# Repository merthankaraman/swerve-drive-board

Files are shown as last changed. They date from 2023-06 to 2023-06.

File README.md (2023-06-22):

# Swerve Drive Mobile Robot Board
### Schematic Of the Shield V2
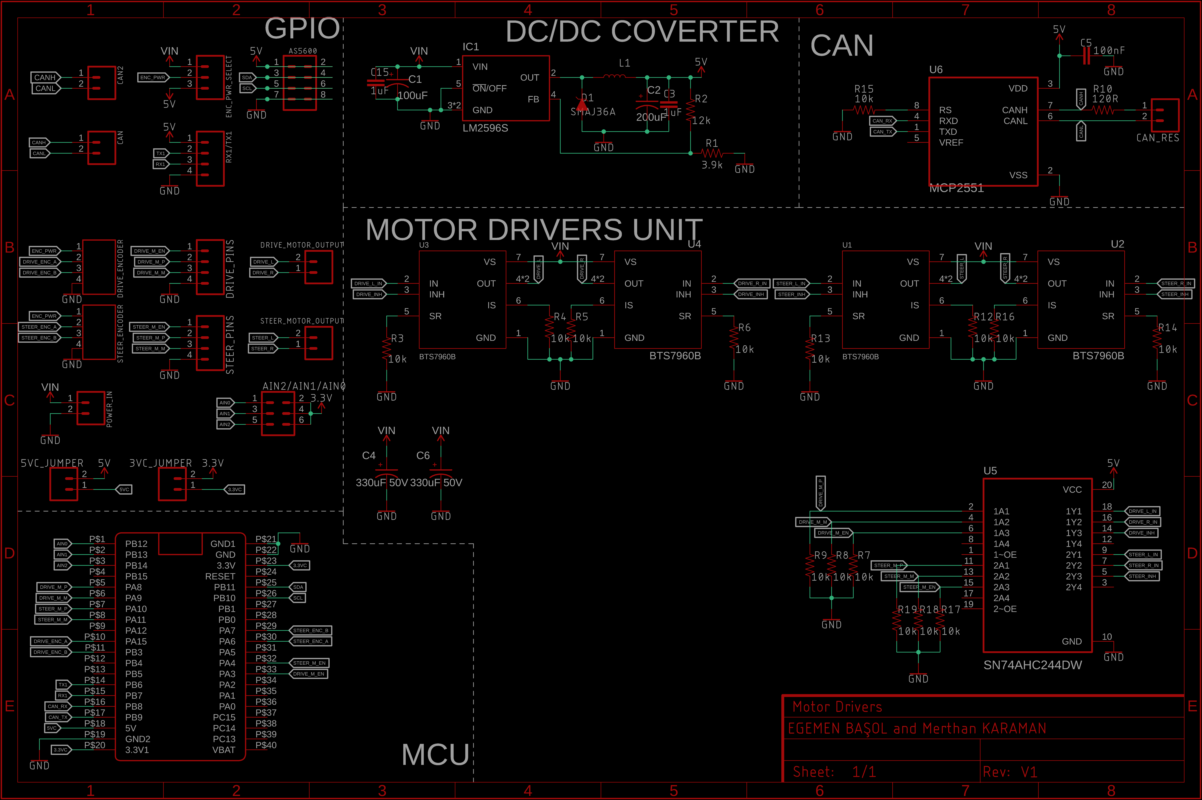
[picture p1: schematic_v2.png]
<br/><br/>

### Board Of the Shield V2
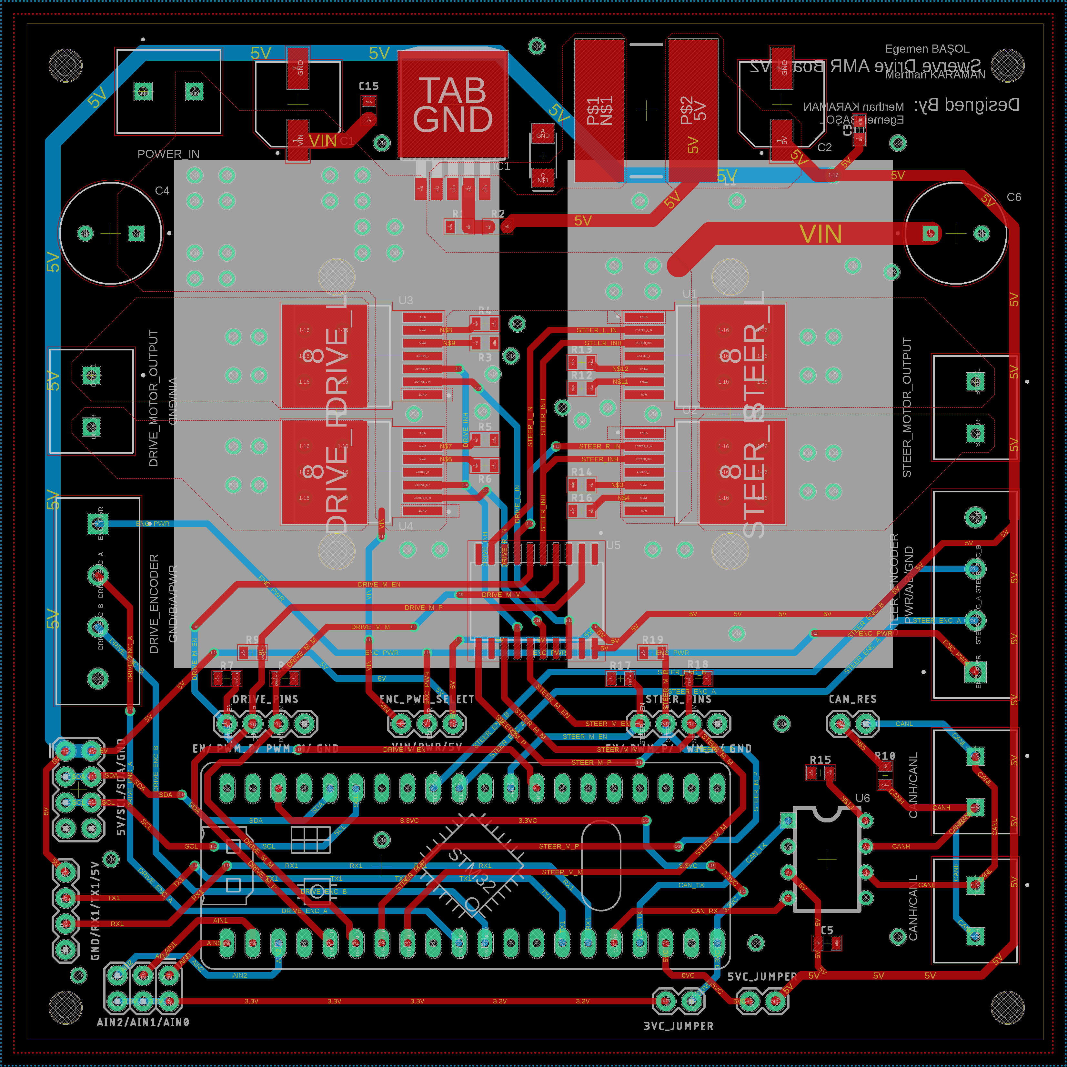
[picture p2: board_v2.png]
<br/><br/>

### Schematic Of the Shield V1
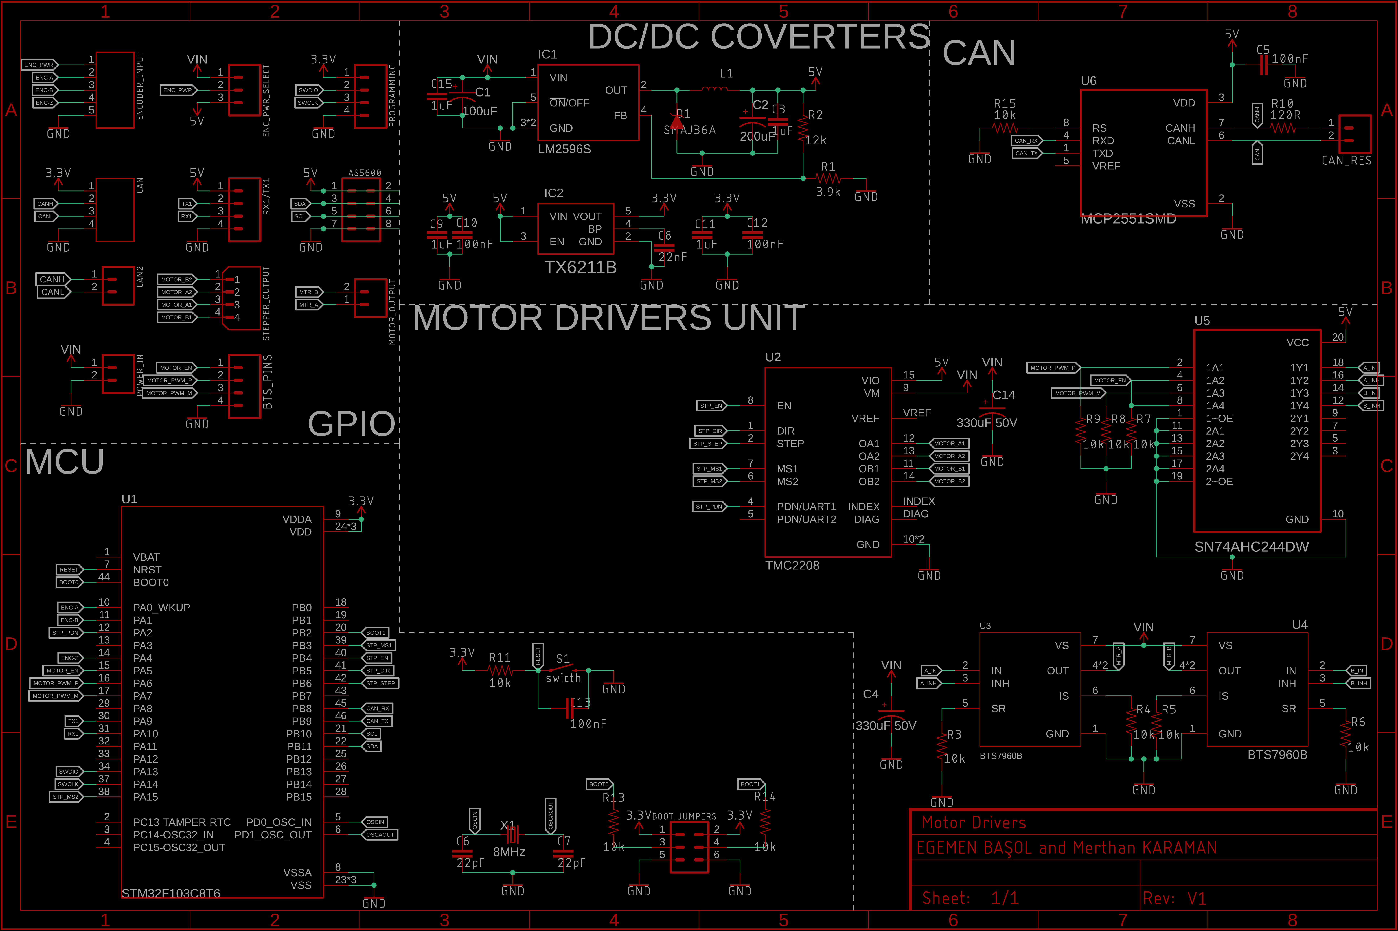
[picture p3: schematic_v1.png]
<br/><br/>

### Board Of the Shield V1
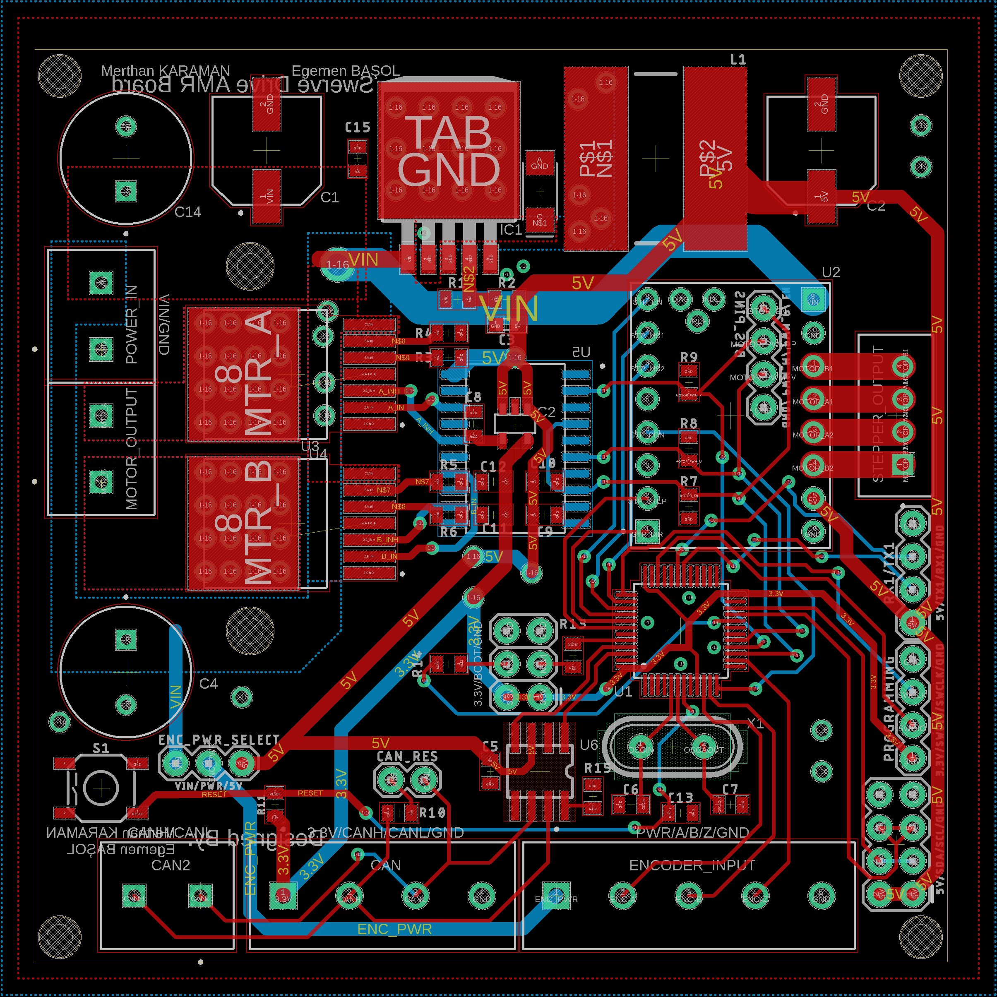
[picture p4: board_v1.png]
<br/><br/>

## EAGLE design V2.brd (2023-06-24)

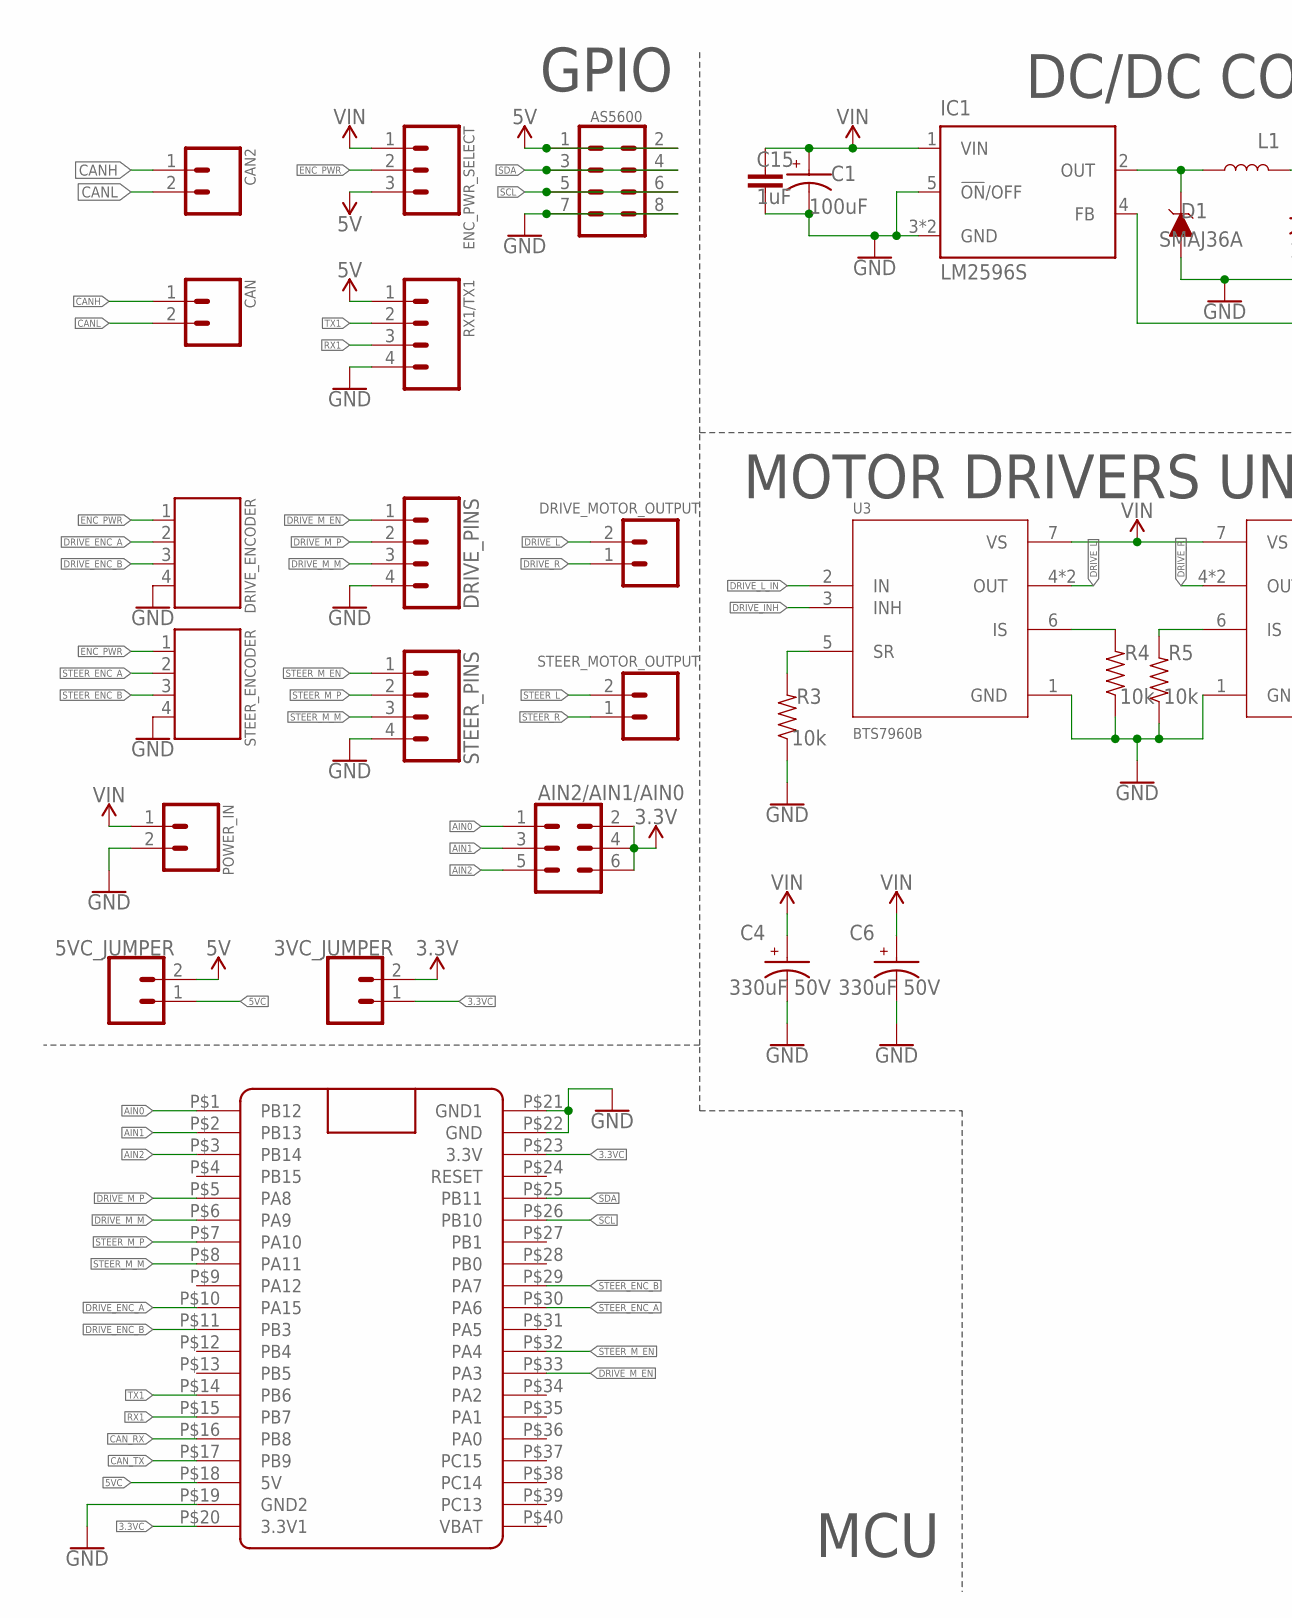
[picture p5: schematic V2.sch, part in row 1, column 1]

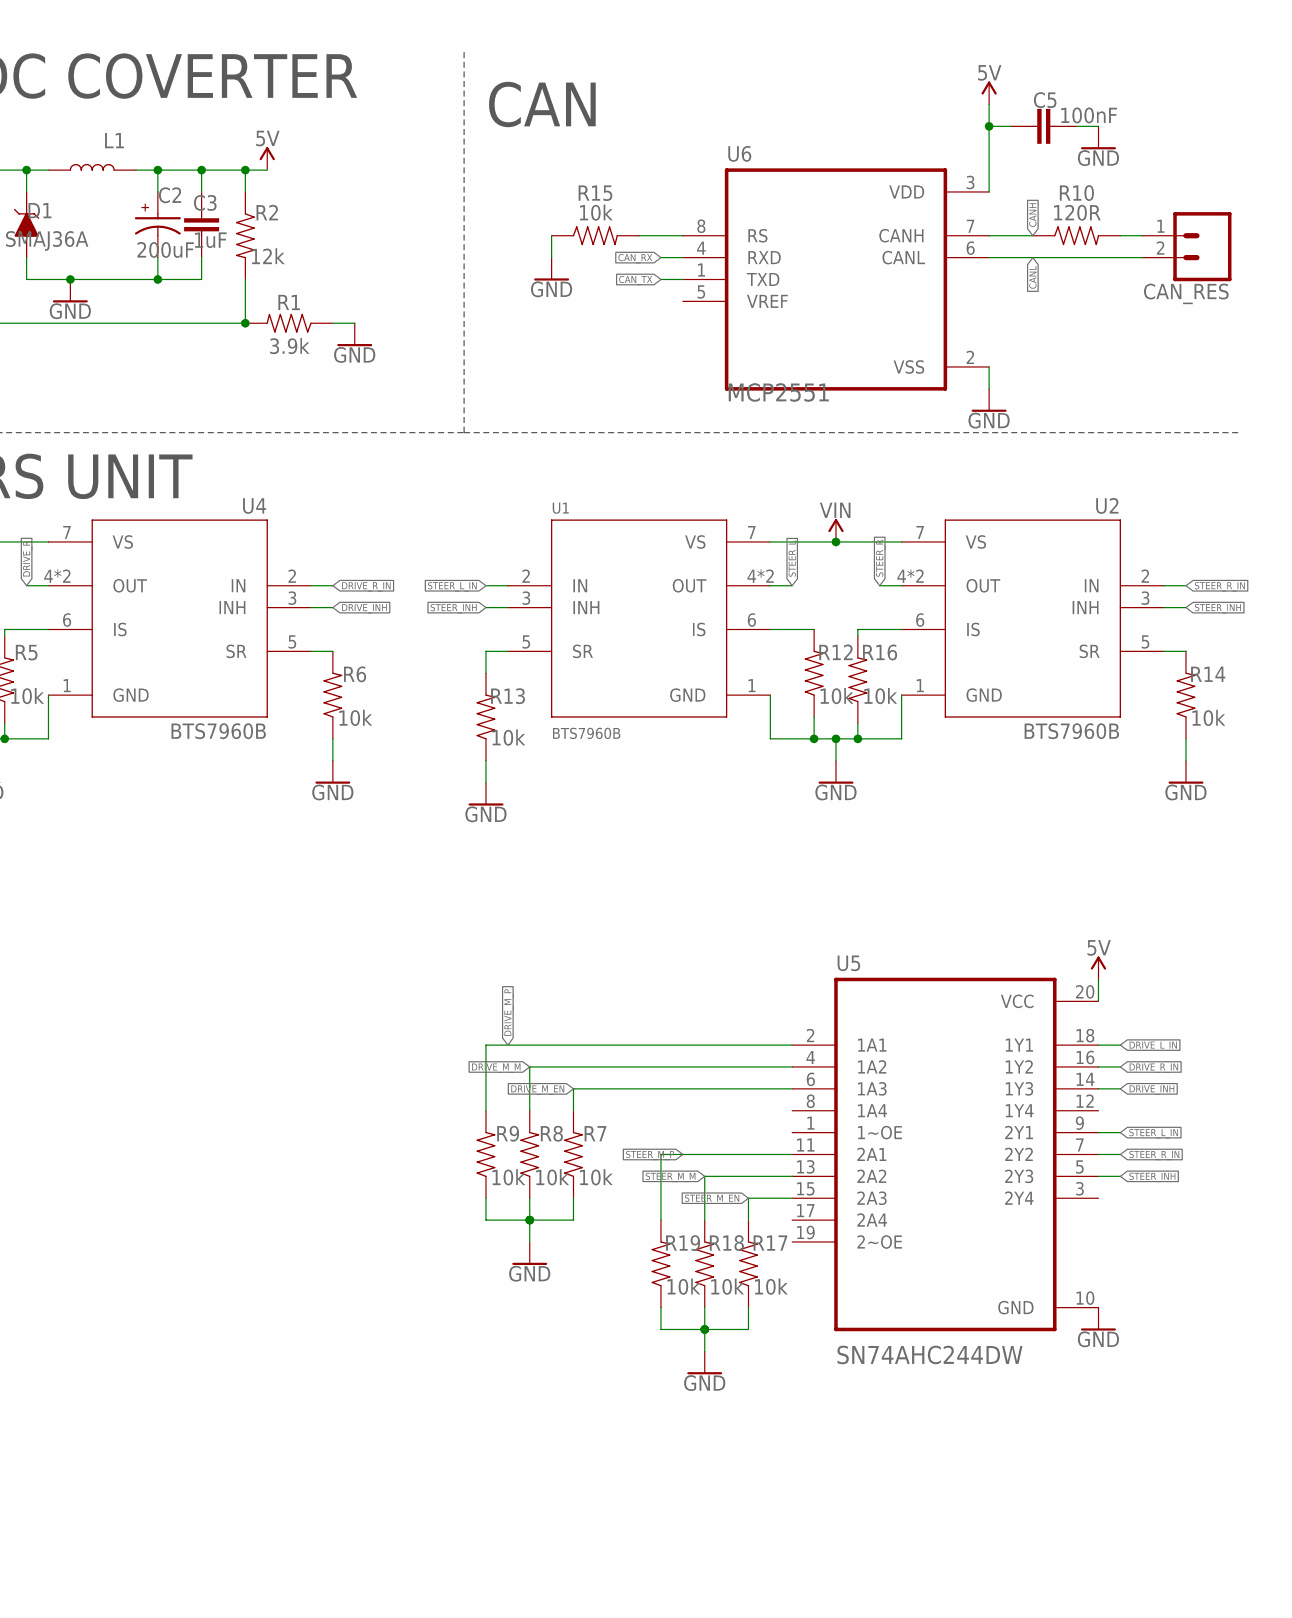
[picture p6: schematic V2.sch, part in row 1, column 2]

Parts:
3VC_JUMPER, 5VC_JUMPER: CONN_02; 1X02
AIN2/AIN1/AIN0: CONN_03X2FEMALE; 2X3
AS5600: 5V/SCL/SDA/GND; 2X4
C1: 100uF; CPOL-SMD
C2: 200uF; CPOL-SMD
C3: 1uF; 0603
C4, C6: 330uF 50V; CPOL-RADIAL-5MM-10MM
C5: 100nF; 0805
C15: 1uF; 0805
CAN, CAN2: CANH/CANL; 5.08MM_2PIN
CAN_RES: CONN_02; 1X02
D1: SMAJ36A; DO-214AC
DRIVE_ENCODER: GND/B/A/PWR; 5.08MM_4PIN
DRIVE_MOTOR_OUTPUT: 5.08MM_2PIN
DRIVE_PINS: EN/ PWM_P/ PWM_M/ GND; 1X04
ENC_PWR_SELECT: VIN/PWR/5V; 1X03
IC1: LM2596S; TO263-5
L1: 47uH; COIL_14X14
POWER_IN: VIN/GND; 5.08MM_2PIN
R1: 3.9k; 0805
R2: 12k; 0805
R3, R4, R5, R6, R7, R8, R9, R12, R13, R14, R15, R16, R17, R18, R19: 10k; 0805
R10: 120R; 0805
RX1/TX1: GND/RX1/TX1/5V; 1X04
STEER_ENCODER: PWR/A/B/GND; 5.08MM_4PIN
STEER_MOTOR_OUTPUT: 5.08MM_2PIN
STEER_PINS: EN/ PWM_P/ PWM_M/ GND; 1X04
U1, U2, U3, U4: BTS7960B; DPAK127P1490X440-8N
U5: SN74AHC244DW; SOIC127P1030X265-20N
U6: MCP2551; DIP-8
U$1: BLUE_PILL

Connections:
3.3V: 3VC_JUMPER.2, AIN2/AIN1/AIN0.2, AIN2/AIN1/AIN0.4, AIN2/AIN1/AIN0.6
3.3VC: 3VC_JUMPER.1, U$1.P$20 (3.3V1), U$1.P$23 (3.3V)
5V: 5VC_JUMPER.2, AS5600.1, AS5600.2, C2.1, C3.2, C5.2, ENC_PWR_SELECT.3, L1.P$2 (2), R2.1, RX1/TX1.1, U5.20 (VCC), U6.3 (VDD)
5VC: 5VC_JUMPER.1, U$1.P$18 (5V)
AIN0: AIN2/AIN1/AIN0.1, U$1.P$1 (PB12)
AIN1: AIN2/AIN1/AIN0.3, U$1.P$2 (PB13)
AIN2: AIN2/AIN1/AIN0.5, U$1.P$3 (PB14)
CANH: CAN.1, CAN2.1, R10.1, U6.7 (CANH)
CANL: CAN.2, CAN2.2, CAN_RES.2, U6.6 (CANL)
CAN_RX: U6.4 (RXD), U$1.P$16 (PB8)
CAN_TX: U6.1 (TXD), U$1.P$17 (PB9)
DRIVE_ENC_A: DRIVE_ENCODER.2, U$1.P$10 (PA15)
DRIVE_ENC_B: DRIVE_ENCODER.3, U$1.P$11 (PB3)
DRIVE_INH: U3.3 (INH), U4.3 (INH), U5.14 (1Y3)
DRIVE_L: DRIVE_MOTOR_OUTPUT.2, U3.4 (OUT), U3.8 (OUT)
DRIVE_L_IN: U3.2 (IN), U5.18 (1Y1)
DRIVE_M_EN: DRIVE_PINS.1, R7.2, U5.6 (1A3), U$1.P$33 (PA3)
DRIVE_M_M: DRIVE_PINS.3, R8.2, U5.4 (1A2), U$1.P$6 (PA9)
DRIVE_M_P: DRIVE_PINS.2, R9.2, U5.2 (1A1), U$1.P$5 (PA8)
DRIVE_R: DRIVE_MOTOR_OUTPUT.1, U4.4 (OUT), U4.8 (OUT)
DRIVE_R_IN: U4.2 (IN), U5.16 (1Y2)
ENC_PWR: DRIVE_ENCODER.1, ENC_PWR_SELECT.2, STEER_ENCODER.1
GND: AS5600.7, AS5600.8, C1.2, C2.2, C3.1, C4.N, C5.1, C6.N, C15.1, D1.A, DRIVE_ENCODER.4, DRIVE_PINS.4, IC1.3 (GND), IC1.5 (!ON!/OFF), IC1.TAB (GND), POWER_IN.2, R1.1, R3.1, R4.1, R5.1, R6.1, R7.1, R8.1, R9.1, R12.1, R13.1, R14.1, R15.1, R16.1, R17.1, R18.1, R19.1, RX1/TX1.4, STEER_ENCODER.4, STEER_PINS.4, U1.1 (GND), U2.1 (GND), U3.1 (GND), U4.1 (GND), U5.10 (GND), U6.2 (VSS), U$1.P$19 (GND2), U$1.P$21 (GND1), U$1.P$22 (GND)
unnamed: D1.C, IC1.2 (OUT), L1.P$1 (1)
unnamed: IC1.4 (FB), R1.2, R2.2
unnamed: R14.2, U2.5 (SR)
unnamed: R16.2, U2.6 (IS)
unnamed: CAN_RES.1, R10.2
unnamed: R6.2, U4.5 (SR)
unnamed: R5.2, U4.6 (IS)
unnamed: R4.2, U3.6 (IS)
unnamed: R3.2, U3.5 (SR)
unnamed: R12.2, U1.6 (IS)
unnamed: R13.2, U1.5 (SR)
unnamed: R15.2, U6.8 (RS)
RX1: RX1/TX1.3, U$1.P$15 (PB7)
SCL: AS5600.5, AS5600.6, U$1.P$26 (PB10)
SDA: AS5600.3, AS5600.4, U$1.P$25 (PB11)
STEER_ENC_A: STEER_ENCODER.2, U$1.P$30 (PA6)
STEER_ENC_B: STEER_ENCODER.3, U$1.P$29 (PA7)
STEER_INH: U1.3 (INH), U2.3 (INH), U5.5 (2Y3)
STEER_L: STEER_MOTOR_OUTPUT.2, U1.4 (OUT), U1.8 (OUT)
STEER_L_IN: U1.2 (IN), U5.9 (2Y1)
STEER_M_EN: R17.2, STEER_PINS.1, U5.15 (2A3), U$1.P$32 (PA4)
STEER_M_M: R18.2, STEER_PINS.3, U5.13 (2A2), U$1.P$8 (PA11)
STEER_M_P: R19.2, STEER_PINS.2, U5.11 (2A1), U$1.P$7 (PA10)
STEER_R: STEER_MOTOR_OUTPUT.1, U2.4 (OUT), U2.8 (OUT)
STEER_R_IN: U2.2 (IN), U5.7 (2Y2)
TX1: RX1/TX1.2, U$1.P$14 (PB6)
VIN: C1.1, C4.P, C6.P, C15.2, ENC_PWR_SELECT.1, IC1.1 (VIN), POWER_IN.1, U1.7 (VS), U2.7 (VS), U3.7 (VS), U4.7 (VS)

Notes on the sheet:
MCU
CAN
DC/DC COVERTER
GPIO
MOTOR DRIVERS UNIT

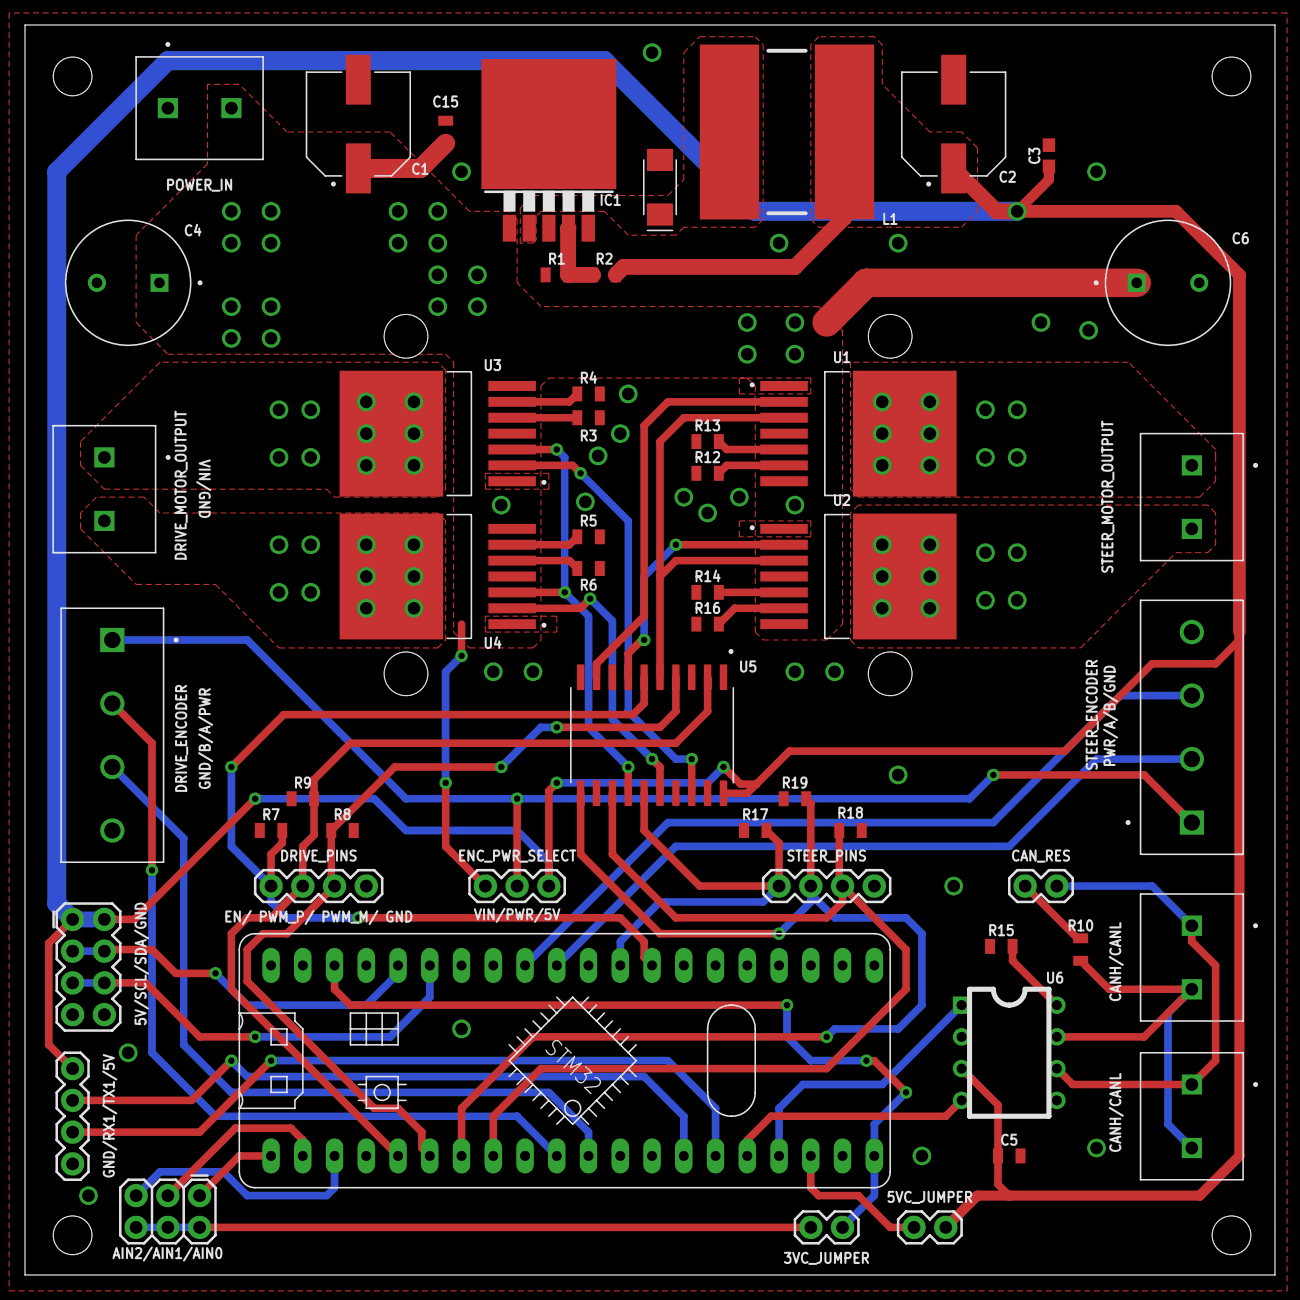
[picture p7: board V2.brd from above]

Board: 2 copper layers, 100.0 x 100.0 mm, 53 parts (0 on the bottom side), 50 nets.

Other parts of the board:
U$2, U$3: BTS_HEATER

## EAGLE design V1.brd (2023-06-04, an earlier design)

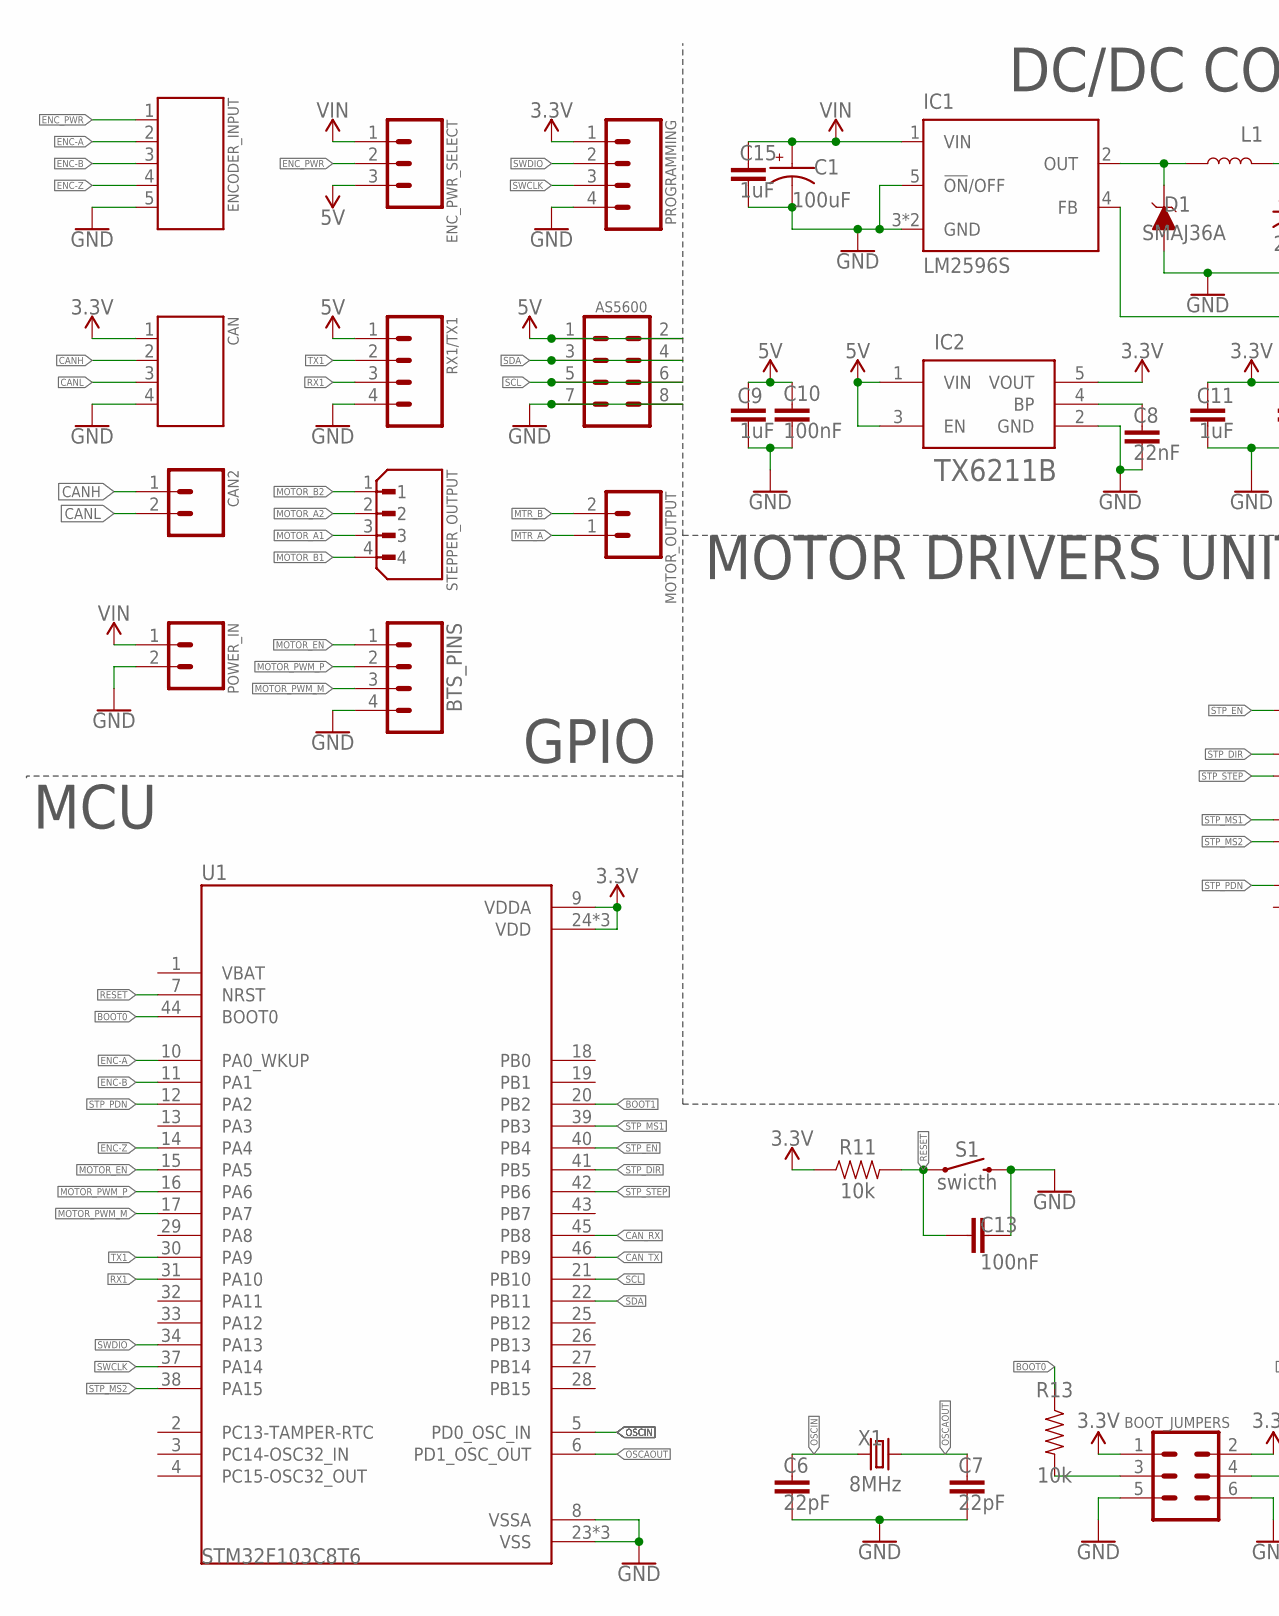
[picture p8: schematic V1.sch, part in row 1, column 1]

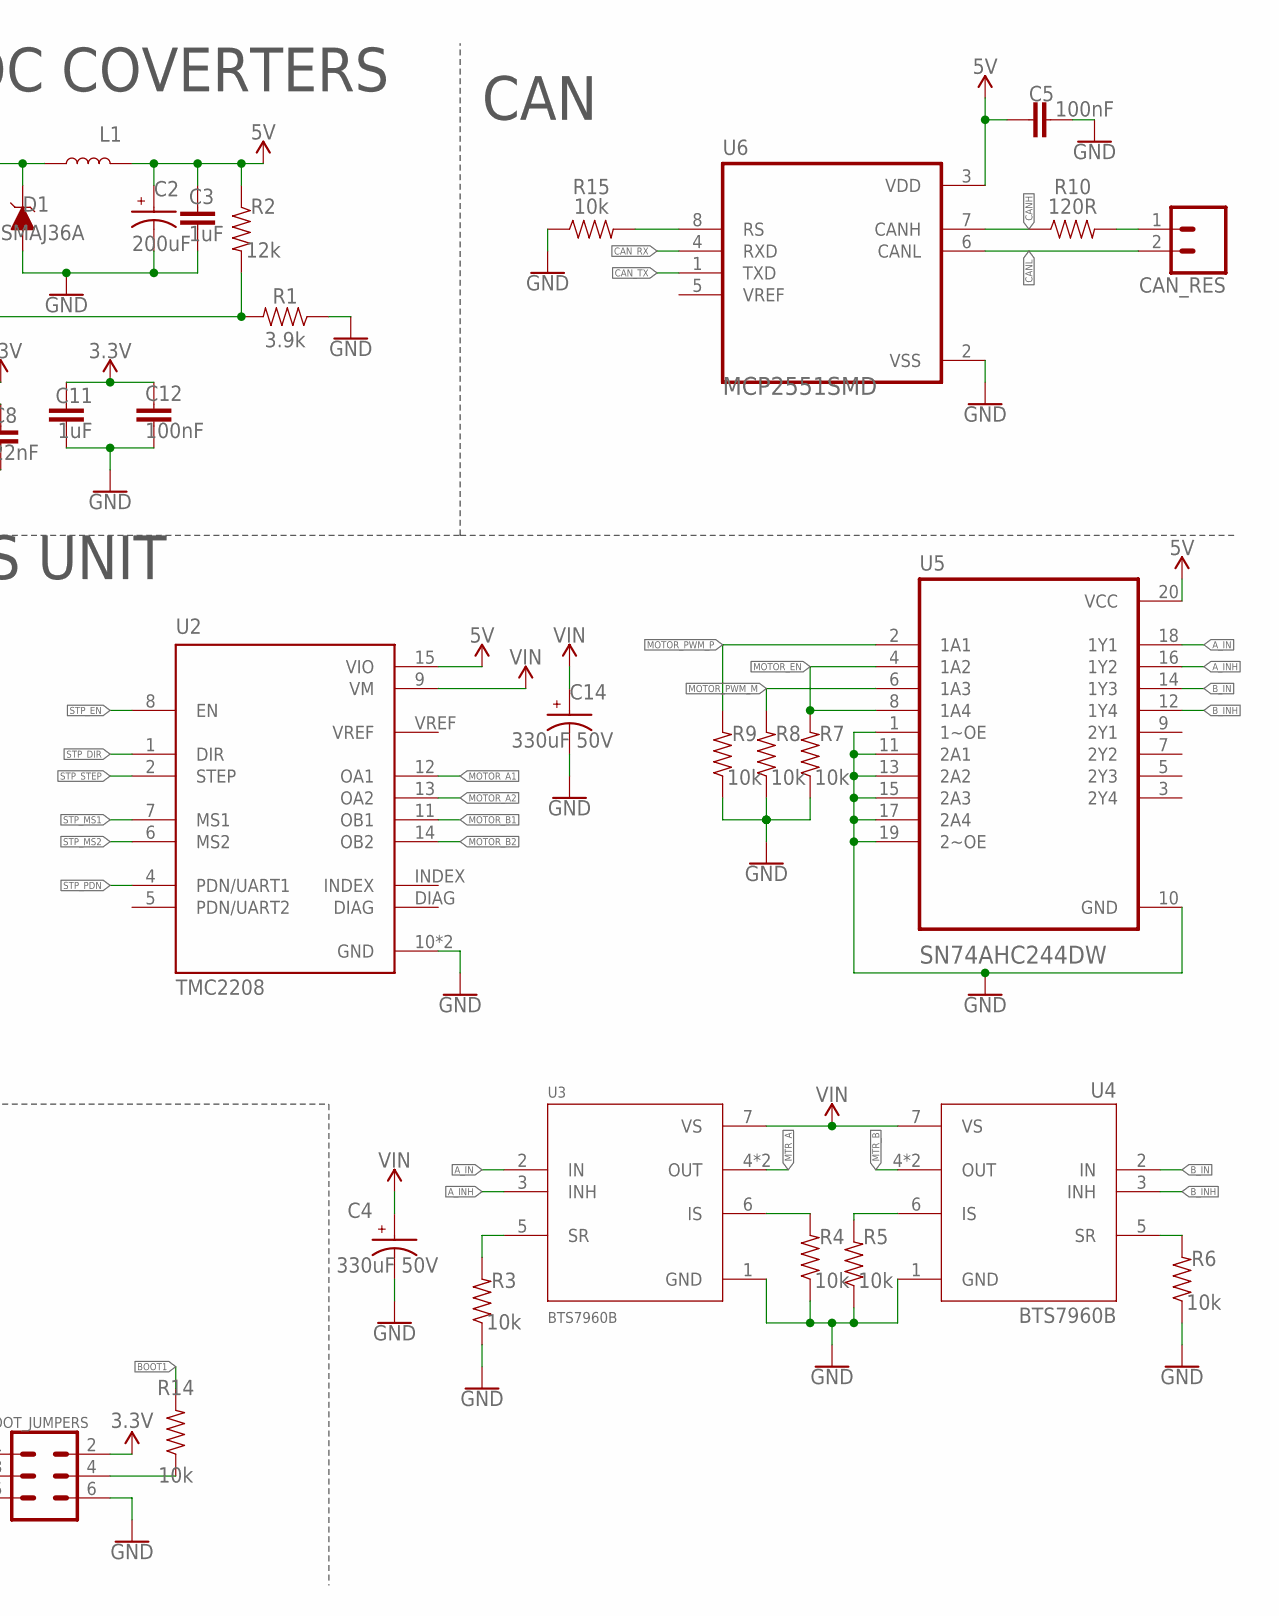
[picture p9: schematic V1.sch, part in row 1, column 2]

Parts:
AS5600: 5V/SDA/SCL/GND; 2X4
BOOT_JUMPERS: CONN_03X2FEMALE; 2X3
BTS_PINS: GND/ PWM_M/ PWM_P/ EN; 1X04
C1: 100uF; CPOL-SMD
C2: 200uF; CPOL-SMD
C3: 1uF; 0603
C4, C14: 330uF 50V; CPOL-RADIAL-5MM-10MM
C5, C10, C12, C13: 100nF; 0805
C6, C7: 22pF; 0805
C8: 22nF; 0805
C9, C11, C15: 1uF; 0805
CAN: 3.3V/CANH/CANL/GND; 5.08MM_4PIN
CAN2: CANH/CANL; 5.08MM_2PIN
CAN_RES: CONN_02; 1X02
D1: SMAJ36A; DO-214AC
ENCODER_INPUT: PWR/A/B/Z/GND; 5.08MM_5PIN
ENC_PWR_SELECT: VIN/PWR/5V; 1X03
IC1: LM2596S; TO263-5
IC2: TX6211B; SOT23-5
L1: 47uH; COIL_14X14
MOTOR_OUTPUT: 5.08MM_2PIN
POWER_IN: VIN/GND; 5.08MM_2PIN
PROGRAMMING: 3.3V/SWDIO/SWCLK/GND; 1X04
R1: 3.9k; 0805
R2: 12k; 0805
R3, R4, R5, R6, R7, R8, R9, R11, R13, R14, R15: 10k; 0805
R10: 120R; 0805
RX1/TX1: 5V/TX1/RX1/GND; 1X04
S1: swicth; TACTILE_SWITCH_SMD_5.2MM
STEPPER_OUTPUT: 4PIN_TUNIC_2.5MM; JST_B4B-XH-A(LF)(SN)
U1: STM32F103C8T6; LQFP-48
U2: TMC2208; MODULE_TMC2208_SILENTSTEPSTICK
U3, U4: BTS7960B; DPAK127P1490X440-8N
U5: SN74AHC244DW; SOIC127P1030X265-20N
U6: MCP2551SMD; SOIC-8
X1: 8MHz; HC49

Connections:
3.3V: BOOT_JUMPERS.1, BOOT_JUMPERS.2, C11.2, C12.2, CAN.1, IC2.5 (VOUT), PROGRAMMING.1, R11.1, U1.9 (VDDA), U1.24 (VDD), U1.36 (VDD), U1.48 (VDD)
5V: AS5600.1, AS5600.2, C2.1, C3.2, C5.2, C9.2, C10.2, ENC_PWR_SELECT.3, IC2.1 (VIN), IC2.3 (EN), L1.P$2 (2), R2.1, RX1/TX1.1, U2.15 (VIO), U5.20 (VCC), U6.3 (VDD)
A_IN: U3.2 (IN), U5.18 (1Y1)
A_INH: U3.3 (INH), U5.16 (1Y2)
BOOT0: R13.1, U1.44 (BOOT0)
BOOT1: R14.2, U1.20 (PB2)
B_IN: U4.2 (IN), U5.14 (1Y3)
B_INH: U4.3 (INH), U5.12 (1Y4)
CANH: CAN.2, CAN2.1, R10.1, U6.7 (CANH)
CANL: CAN.3, CAN2.2, CAN_RES.2, U6.6 (CANL)
CAN_RX: U1.45 (PB8), U6.4 (RXD)
CAN_TX: U1.46 (PB9), U6.1 (TXD)
ENC-A: ENCODER_INPUT.2, U1.10 (PA0_WKUP)
ENC-B: ENCODER_INPUT.3, U1.11 (PA1)
ENC-Z: ENCODER_INPUT.4, U1.14 (PA4)
ENC_PWR: ENCODER_INPUT.1, ENC_PWR_SELECT.2
GND: AS5600.7, AS5600.8, BOOT_JUMPERS.5, BOOT_JUMPERS.6, BTS_PINS.4, C1.2, C2.2, C3.1, C4.N, C5.1, C6.1, C7.1, C8.1, C9.1, C10.1, C11.1, C12.1, C13.1, C14.N, C15.1, CAN.4, D1.A, ENCODER_INPUT.5, IC1.3 (GND), IC1.5 (!ON!/OFF), IC1.TAB (GND), IC2.2 (GND), POWER_IN.2, PROGRAMMING.4, R1.1, R3.1, R4.1, R5.1, R6.1, R7.1, R8.1, R9.1, R15.1, RX1/TX1.4, S1.3 (2), U1.8 (VSSA), U1.23 (VSS), U1.35 (VSS), U1.47 (VSS), U2.10 (GND), U2.16 (GND), U3.1 (GND), U4.1 (GND), U5.1 (1~OE), U5.10 (GND), U5.11 (2A1), U5.13 (2A2), U5.15 (2A3), U5.17 (2A4), U5.19 (2~OE), U6.2 (VSS)
MOTOR_A1: STEPPER_OUTPUT.3, U2.12 (OA1)
MOTOR_A2: STEPPER_OUTPUT.2, U2.13 (OA2)
MOTOR_B1: STEPPER_OUTPUT.4, U2.11 (OB1)
MOTOR_B2: STEPPER_OUTPUT.1, U2.14 (OB2)
MOTOR_EN: BTS_PINS.1, R7.2, U1.15 (PA5), U5.4 (1A2), U5.8 (1A4)
MOTOR_PWM_M: BTS_PINS.3, R8.2, U1.17 (PA7), U5.6 (1A3)
MOTOR_PWM_P: BTS_PINS.2, R9.2, U1.16 (PA6), U5.2 (1A1)
MTR_A: MOTOR_OUTPUT.1, U3.4 (OUT), U3.8 (OUT)
MTR_B: MOTOR_OUTPUT.2, U4.4 (OUT), U4.8 (OUT)
unnamed: D1.C, IC1.2 (OUT), L1.P$1 (1)
unnamed: IC1.4 (FB), R1.2, R2.2
unnamed: CAN_RES.1, R10.2
unnamed: R6.2, U4.5 (SR)
unnamed: R5.2, U4.6 (IS)
unnamed: R4.2, U3.6 (IS)
unnamed: R3.2, U3.5 (SR)
unnamed: C8.2, IC2.4 (BP)
unnamed: BOOT_JUMPERS.4, R14.1
unnamed: R15.2, U6.8 (RS)
unnamed: BOOT_JUMPERS.3, R13.2
OSCAOUT: C7.2, U1.6 (PD1_OSC_OUT), X1.2
OSCIN: C6.2, U1.5 (PD0_OSC_IN), X1.1
RESET: C13.2, R11.2, S1.1, U1.7 (NRST)
RX1: RX1/TX1.3, U1.31 (PA10)
SCL: AS5600.5, AS5600.6, U1.21 (PB10)
SDA: AS5600.3, AS5600.4, U1.22 (PB11)
STP_DIR: U1.41 (PB5), U2.1 (DIR)
STP_EN: U1.40 (PB4), U2.8 (EN)
STP_MS1: U1.39 (PB3), U2.7 (MS1)
STP_MS2: U1.38 (PA15), U2.6 (MS2)
STP_PDN: U1.12 (PA2), U2.4 (PDN/UART1)
STP_STEP: U1.42 (PB6), U2.2 (STEP)
SWCLK: PROGRAMMING.3, U1.37 (PA14)
SWDIO: PROGRAMMING.2, U1.34 (PA13)
TX1: RX1/TX1.2, U1.30 (PA9)
VIN: C1.1, C4.P, C14.P, C15.2, ENC_PWR_SELECT.1, IC1.1 (VIN), POWER_IN.1, U2.9 (VM), U3.7 (VS), U4.7 (VS)

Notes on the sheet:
MCU
CAN
DC/DC COVERTERS
GPIO
MOTOR DRIVERS UNIT

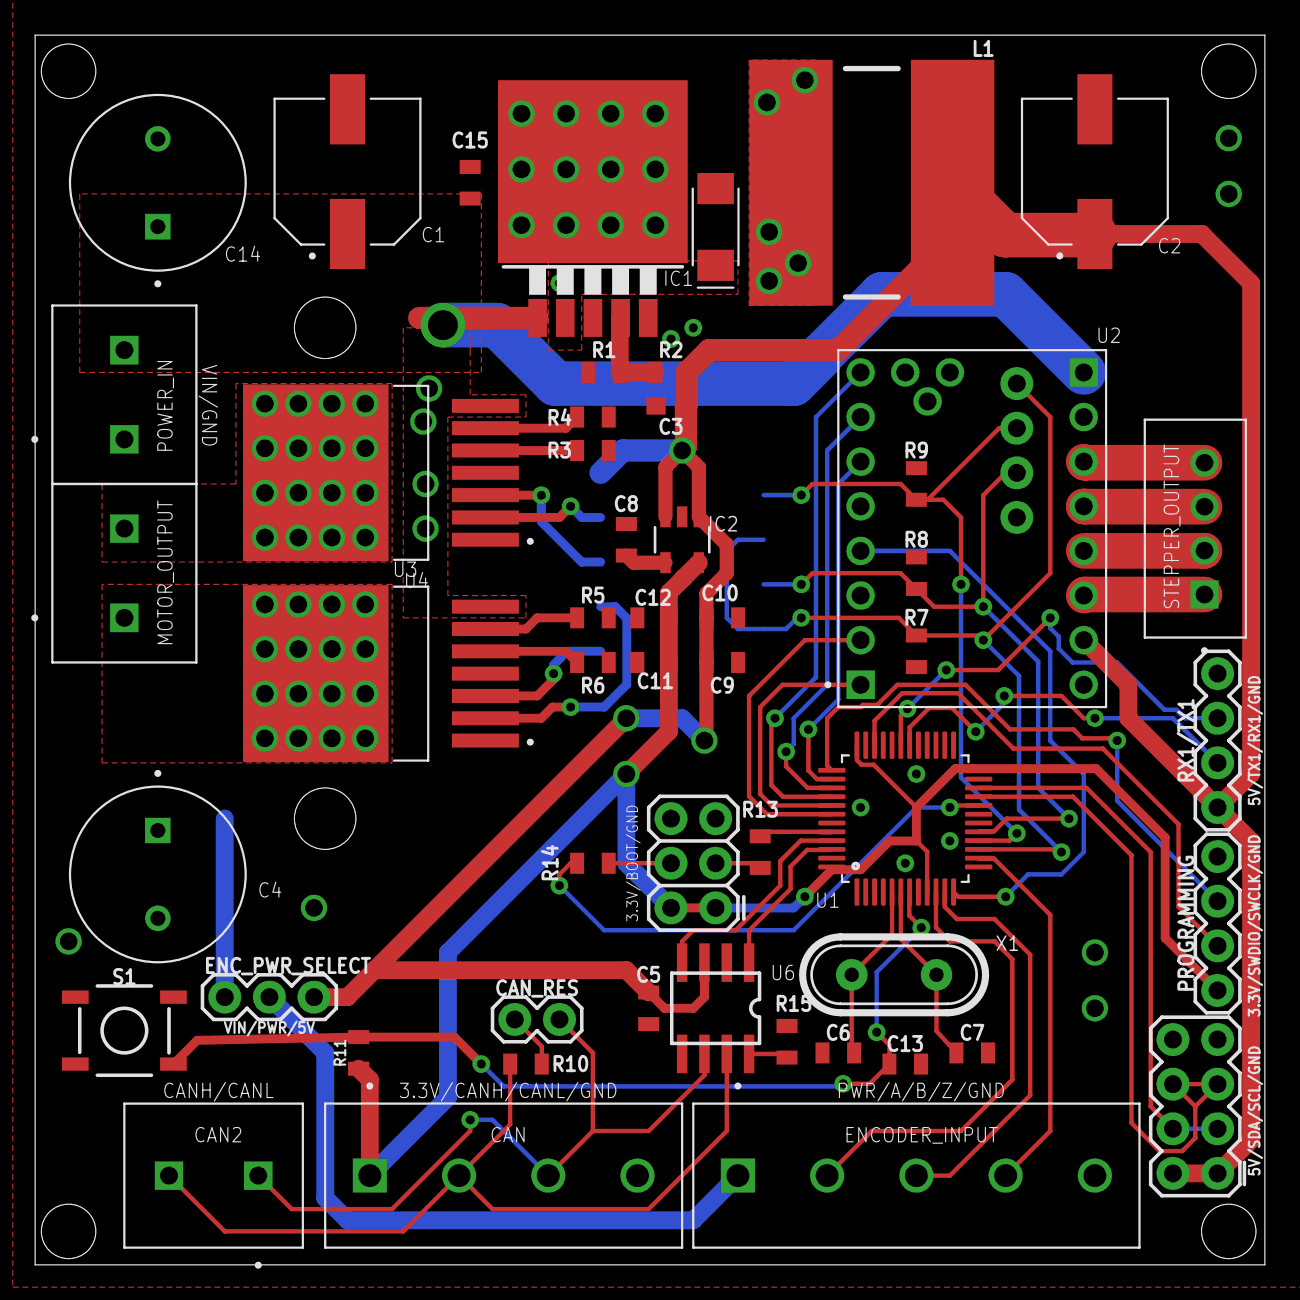
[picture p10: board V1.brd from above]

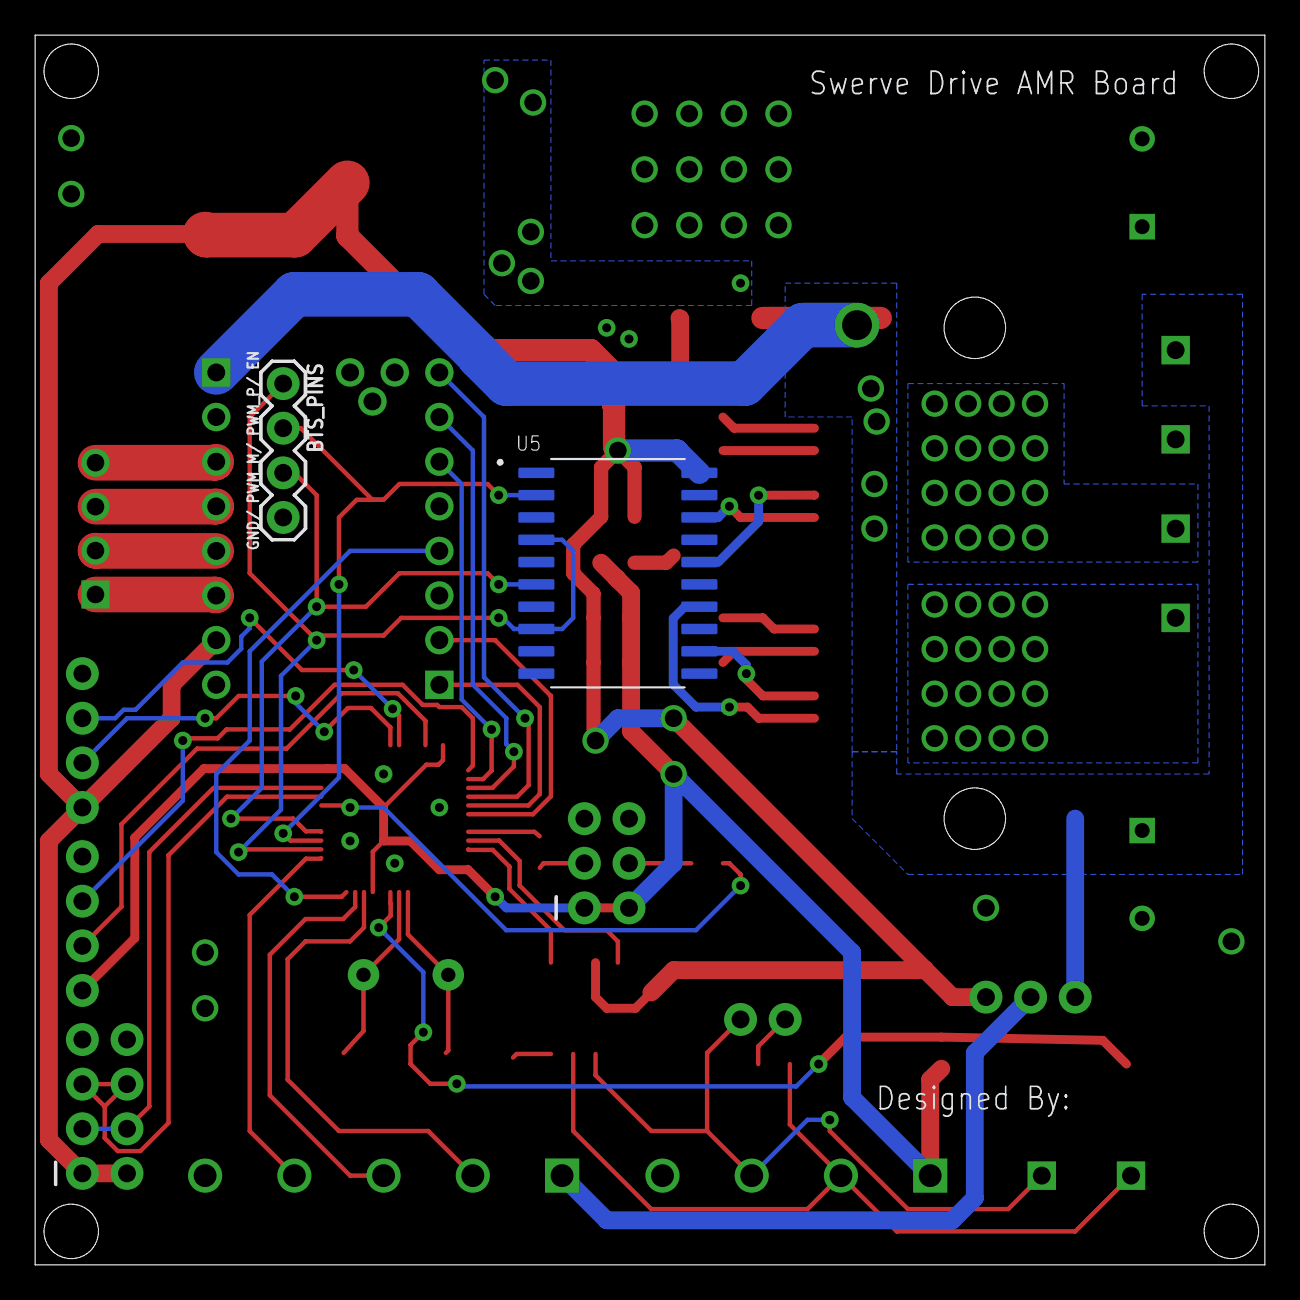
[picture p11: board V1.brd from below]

Board: 2 copper layers, 70.0 x 70.0 mm, 54 parts (2 on the bottom side), 53 nets.

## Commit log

2023-06-21 Almost ended V2. Review required
    [V2.brd, V2.sch]
2023-06-22 V2 finished
    [V2.brd, V2.sch]
2023-06-24 Fixed minor design problems
    [V2.brd, V2.sch]

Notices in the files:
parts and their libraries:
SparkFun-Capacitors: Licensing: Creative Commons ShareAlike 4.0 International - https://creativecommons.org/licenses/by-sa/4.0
